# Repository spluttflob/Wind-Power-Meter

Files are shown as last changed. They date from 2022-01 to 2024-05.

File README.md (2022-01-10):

# Wind-Power-Meter
Hardware and software for a Raspberry Pi hat which measures the power produced by one or two small wind turbines.

## Hardware
The hardware consists of a circuit board designed in the style of a Raspberry
Pi HAT, but it's not an official HAT because an identifier ROM which is part of
the HAT specification isn't present.  Call it a "Cap" or something. 

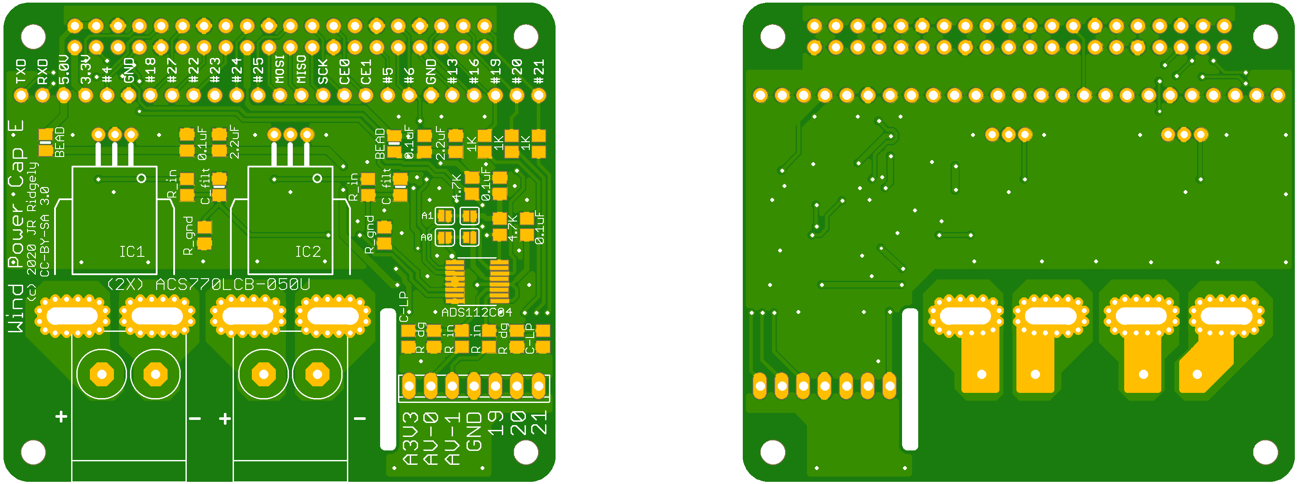
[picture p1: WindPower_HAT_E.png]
Images of Circuit Board


The board was designed in the standalone version of Autodesk&trade; Eagle PCB
and the schematic and board files are in the `hardware` directory.

The board uses a pair of Hall-effect current sensors to measure the current
output of the wind turbine; it is expected that the output will be somewhat
dirty DC, and simple filtering is provided.  Voltage dividers reduce the
voltage output of the turbine to safe levels.  Voltage and current are then
digitized with an ADS112C04 analog to digital converter that talks over an
I<sup>2</sup>C interface with the Raspberry Pi. 

## Software
It's just a Python program which gets data from the ADS112C04 and plots some 
plots. 

The software documentation page is at 
<https://spluttflob.github.io/Wind-Power-Meter/>.

### Pi Setup
When setting up a Raspberry Pi, one must enable the I<sup>2</sup>C interface 
using `raspi-setup` or the **Raspberry Pi Configuration** program from the 
desktop's applications menu.  It's often a good idea to enable **SSH**, the 
**VNC** remote desktop, and **SPI** as well. 

This software is designed to run on a "headless" Raspberry Pi. It has been
tested on the October 2021 release of Raspberry Pi OS. 
There's a nice page showing how to set up a "headless" (no monitor) Raspberry
Pi at 
<https://www.tomshardware.com/reviews/raspberry-pi-headless-setup-how-to,6028.html>.

### Dependencies

One needs the **PySimpleGUI** package for plotting as well as **Matplotlib**. 

* To install Matplotlib, run `sudo apt install python3-matplotlib` on the Pi.

* To install PySimpleGUI, run `sudo pip3 install pysimplegui` on the Pi.

* The web application is still being debugged.  It might help to run 
  `sudo pip3 install pysimpleguiweb htmlparser` on the Pi to begin. 

### VNC Issues
The Remmina client on a Linux PC has problems authenticating with the VNC 
desktop server on the Pi unless one adds the line `Authentication=VncAuth` 
to the file `/root/.vnc/config.d/vncserver-x11` on the Pi and then restarts 
the VNC server on the Pi with a command such as 
`systemctl restart vncserver-x11-serviced` (or a reboot). 

Other clients such as those for Windows&trade; or MacOS&trade; may or may not 
require such action to be taken.

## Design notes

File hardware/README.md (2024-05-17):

# Hardware

Here are a schematic and board layout done in standalone Autodesk&trade; Eagle PCB.
They should be easy to import into the Fusion 260&trade; version of Eagle
or into KiCAD (recommended). 

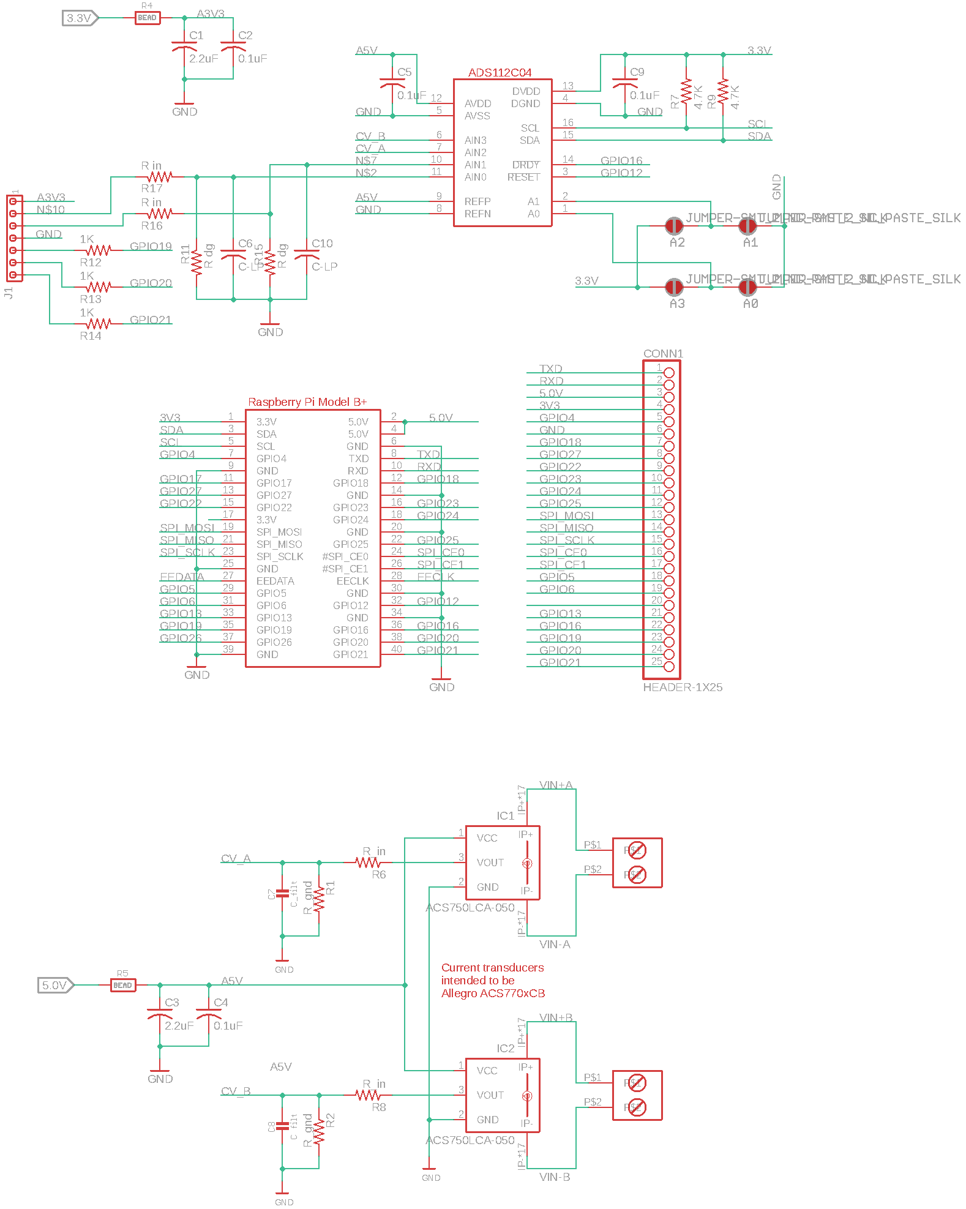
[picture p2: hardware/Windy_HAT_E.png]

_An image of the schematic for somewhat convenient reference._

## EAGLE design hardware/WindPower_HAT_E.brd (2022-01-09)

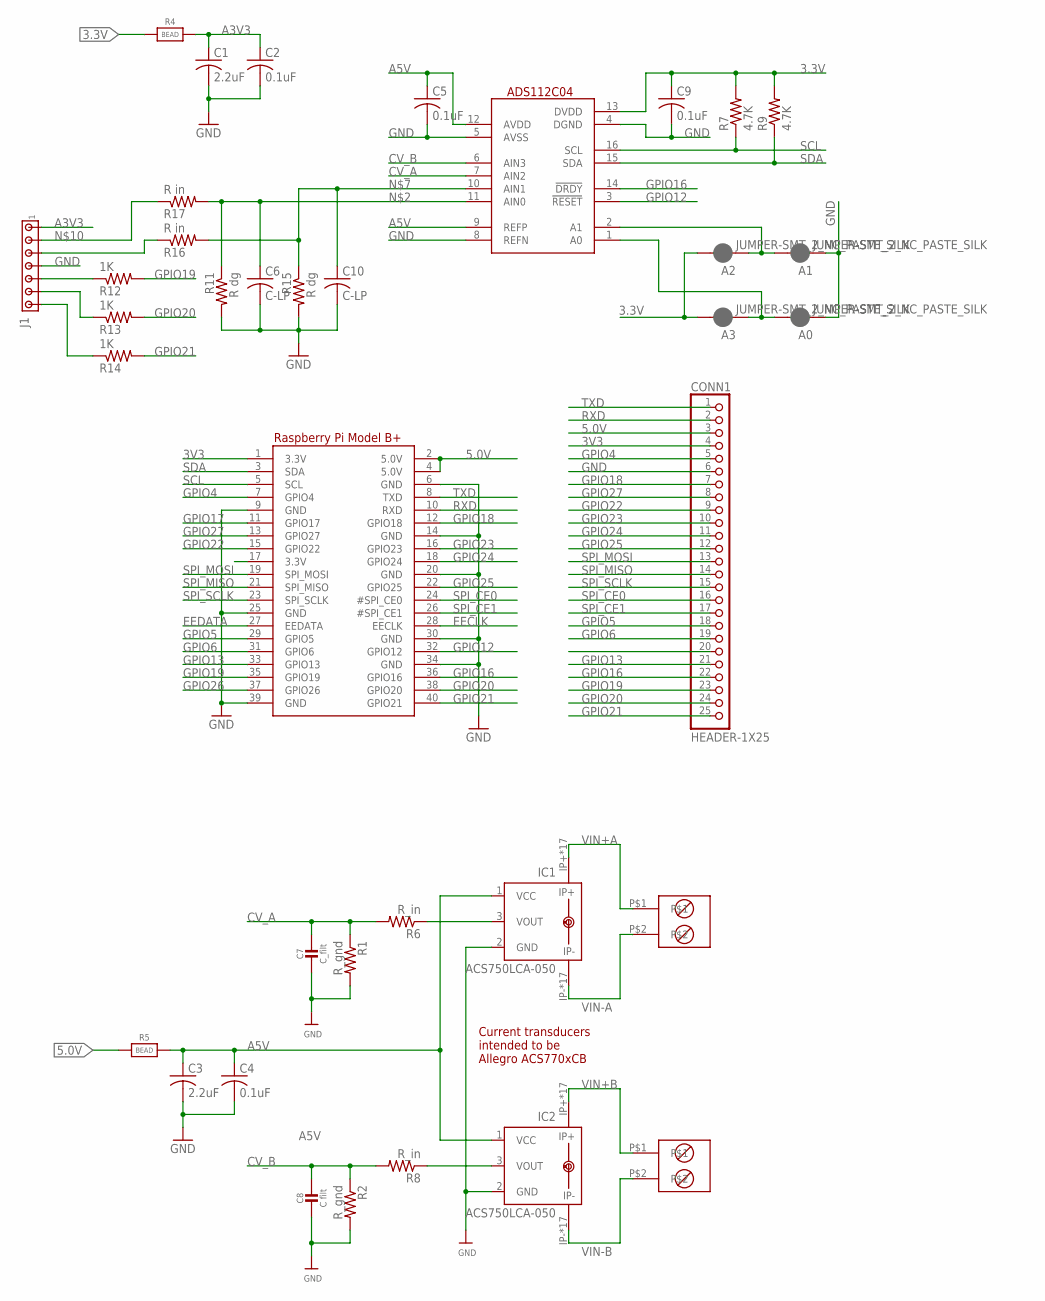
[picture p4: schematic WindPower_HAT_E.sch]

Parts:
A0, A1, A2, A3: JUMPER-SMT_2_NC_PASTE_SILK; SMT-JUMPER_2_NC_PASTE_SILK
ADS112C04: ADS112C04TSSOP_FOR_TI_ADC; SOP65P640X120-16N
C1, C3: 2.2uF; C0805
C2, C4, C5, C9: 0.1uF; C0805
C6, C10: C-LP; C0805
C7: C_filt; 0805-NO@1
C8: C filt; 0805-NO@1
CONN1: HEADER-1X25; 1X25_ROUND_70MIL
IC1, IC2: ACS750LCA-050; ACS75050
J1: MTA07-100; 10X07MTA
R1, R2: R_gnd; R0805
R4, R5: BEAD; 0805-NO
R6, R8: R_in; R0805
R7, R9: 4.7K; R0805
R11, R15: R dg; R0805
R12, R13, R14: 1K; R0805
R16, R17: R in; R0805
RPI1: RASPBERRYPI_BPLUS_HATNOSLOTS; PI_HAT_NOSLOTS
U$4, U$5: SCREW-2-6.35MM; SCREWY-2-6.35MM

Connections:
3.3V: A2.2, A3.2, ADS112C04.13 (DVDD), C9.1, R4.1, R7.2, R9.2, RPI1.17 (3.3V)
3V3: CONN1.4, RPI1.1 (3.3V)
5.0V: CONN1.3, R5.1, RPI1.2 (5.0V), RPI1.4 (5.0V)
A3V3: C1.1, C2.1, J1.1, R4.2
A5V: ADS112C04.9 (REFP), ADS112C04.12 (AVDD), C3.1, C4.1, C5.1, IC1.1 (VCC), IC2.1 (VCC), R5.2
CV_A: ADS112C04.7 (AIN2), C7.1, R1.1, R6.2
CV_B: ADS112C04.6 (AIN3), C8.1, R2.1, R8.2
EECLK: RPI1.28 (EECLK)
EEDATA: RPI1.27 (EEDATA)
GND: A0.1, A1.1, ADS112C04.4 (DGND), ADS112C04.5 (AVSS), ADS112C04.8 (REFN), C1.2, C2.2, C3.2, C4.2, C5.2, C6.2, C7.2, C8.2, C9.2, C10.2, CONN1.6, CONN1.20, IC1.2 (GND), IC2.2 (GND), J1.4, R1.2, R2.2, R11.2, R15.2, RPI1.6 (GND), RPI1.9 (GND), RPI1.14 (GND), RPI1.20 (GND), RPI1.25 (GND), RPI1.30 (GND), RPI1.34 (GND), RPI1.39 (GND)
GPIO4: CONN1.5, RPI1.7 (GPIO4)
GPIO5: CONN1.18, RPI1.29 (GPIO5)
GPIO6: CONN1.19, RPI1.31 (GPIO6)
GPIO12: ADS112C04.3 (!RESET), RPI1.32 (GPIO12)
GPIO13: CONN1.21, RPI1.33 (GPIO13)
GPIO16: ADS112C04.14 (!DRDY), CONN1.22, RPI1.36 (GPIO16)
GPIO17: RPI1.11 (GPIO17)
GPIO18: CONN1.7, RPI1.12 (GPIO18)
GPIO19: CONN1.23, R12.2, RPI1.35 (GPIO19)
GPIO20: CONN1.24, R13.2, RPI1.38 (GPIO20)
GPIO21: CONN1.25, R14.2, RPI1.40 (GPIO21)
GPIO22: CONN1.9, RPI1.15 (GPIO22)
GPIO23: CONN1.10, RPI1.16 (GPIO23)
GPIO24: CONN1.11, RPI1.18 (GPIO24)
GPIO25: CONN1.12, RPI1.22 (GPIO25)
GPIO26: RPI1.37 (GPIO26)
GPIO27: CONN1.8, RPI1.13 (GPIO27)
unnamed: IC1.3 (VOUT), R6.1
unnamed: ADS112C04.11 (AIN0), C6.1, R11.1, R17.2
unnamed: IC2.3 (VOUT), R8.1
unnamed: J1.5, R12.1
unnamed: J1.6, R13.1
unnamed: J1.7, R14.1
unnamed: ADS112C04.10 (AIN1), C10.1, R15.1, R16.2
unnamed: A1.2, A2.1, ADS112C04.2 (A1)
unnamed: A0.2, A3.1, ADS112C04.1 (A0)
unnamed: J1.2, R17.1
unnamed: J1.3, R16.1
RXD: CONN1.2, RPI1.10 (RXD)
SCL: ADS112C04.16 (SCL), R7.1, RPI1.5 (SCL)
SDA: ADS112C04.15 (SDA), R9.1, RPI1.3 (SDA)
SPI_CE0: CONN1.16, RPI1.24 (#SPI_CE0)
SPI_CE1: CONN1.17, RPI1.26 (#SPI_CE1)
SPI_MISO: CONN1.14, RPI1.21 (SPI_MISO)
SPI_MOSI: CONN1.13, RPI1.19 (SPI_MOSI)
SPI_SCLK: CONN1.15, RPI1.23 (SPI_SCLK)
TXD: CONN1.1, RPI1.8 (TXD)
VIN+A: IC1.IP+, IC1.IP+@2 (IP+), IC1.IP+@3 (IP+), IC1.IP+@4 (IP+), IC1.IP+@5 (IP+), IC1.IP+@6 (IP+), IC1.IP+@7 (IP+), IC1.IP+@8 (IP+), IC1.IP+@9 (IP+), IC1.IP+@10 (IP+), IC1.IP+@11 (IP+), IC1.IP+@12 (IP+), IC1.IP+@13 (IP+), IC1.IP+@14 (IP+), IC1.IP+@15 (IP+), IC1.IP+@16 (IP+), IC1.IP+@17 (IP+), U$4.P$1
VIN+B: IC2.IP+, IC2.IP+@2 (IP+), IC2.IP+@3 (IP+), IC2.IP+@4 (IP+), IC2.IP+@5 (IP+), IC2.IP+@6 (IP+), IC2.IP+@7 (IP+), IC2.IP+@8 (IP+), IC2.IP+@9 (IP+), IC2.IP+@10 (IP+), IC2.IP+@11 (IP+), IC2.IP+@12 (IP+), IC2.IP+@13 (IP+), IC2.IP+@14 (IP+), IC2.IP+@15 (IP+), IC2.IP+@16 (IP+), IC2.IP+@17 (IP+), U$5.P$1
VIN-A: IC1.IP-, IC1.IP-@2 (IP-), IC1.IP-@3 (IP-), IC1.IP-@4 (IP-), IC1.IP-@5 (IP-), IC1.IP-@6 (IP-), IC1.IP-@7 (IP-), IC1.IP-@8 (IP-), IC1.IP-@9 (IP-), IC1.IP-@10 (IP-), IC1.IP-@11 (IP-), IC1.IP-@12 (IP-), IC1.IP-@13 (IP-), IC1.IP-@14 (IP-), IC1.IP-@15 (IP-), IC1.IP-@16 (IP-), IC1.IP-@17 (IP-), U$4.P$2
VIN-B: IC2.IP-, IC2.IP-@2 (IP-), IC2.IP-@3 (IP-), IC2.IP-@4 (IP-), IC2.IP-@5 (IP-), IC2.IP-@6 (IP-), IC2.IP-@7 (IP-), IC2.IP-@8 (IP-), IC2.IP-@9 (IP-), IC2.IP-@10 (IP-), IC2.IP-@11 (IP-), IC2.IP-@12 (IP-), IC2.IP-@13 (IP-), IC2.IP-@14 (IP-), IC2.IP-@15 (IP-), IC2.IP-@16 (IP-), IC2.IP-@17 (IP-), U$5.P$2

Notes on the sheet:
Current transducers intended to be Allegro ACS770xCB

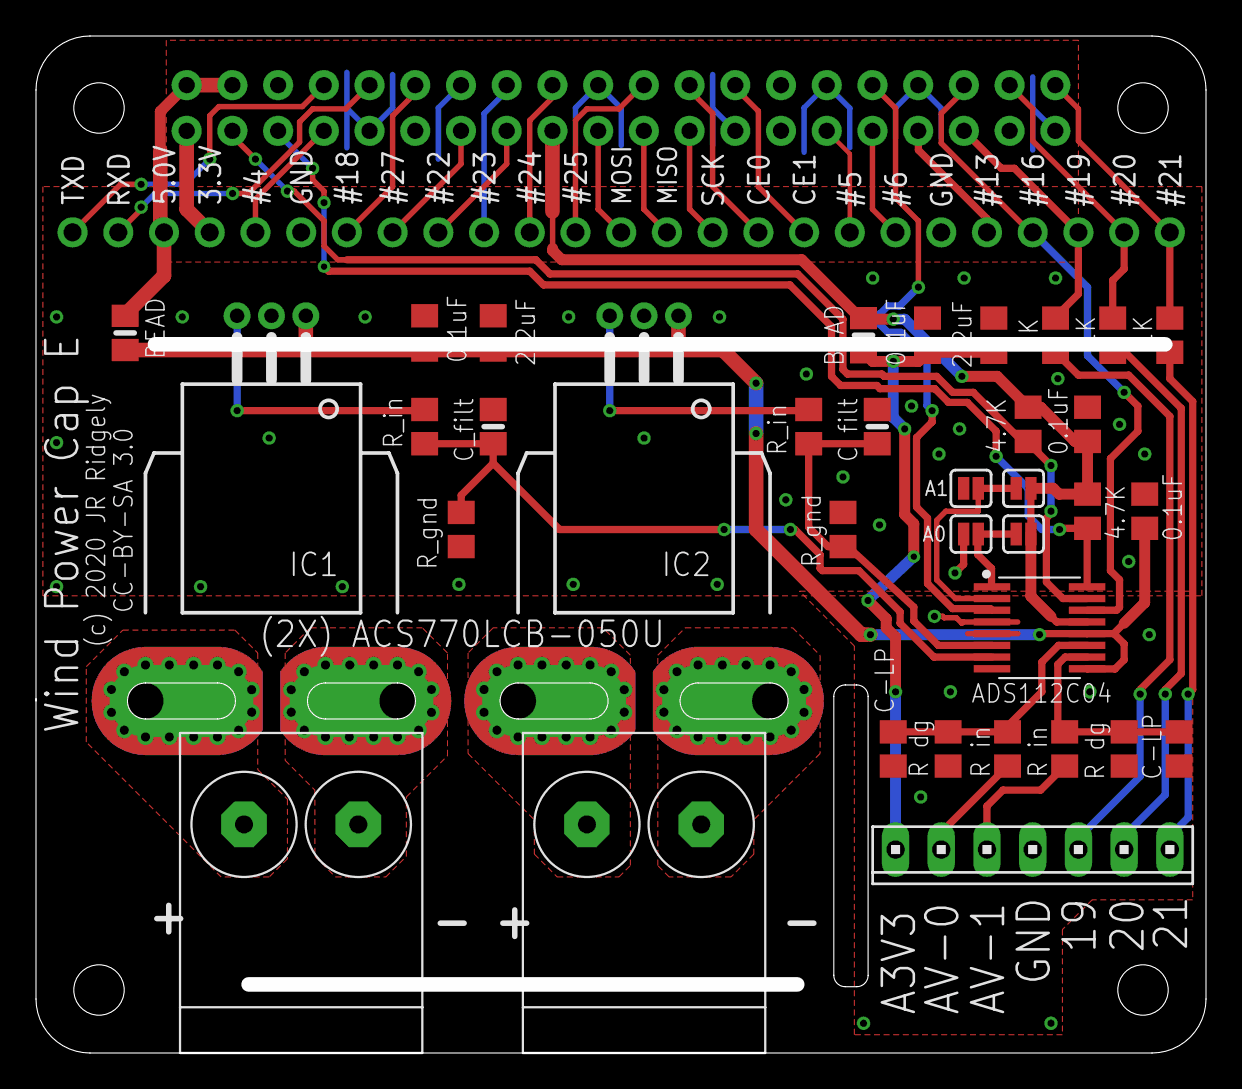
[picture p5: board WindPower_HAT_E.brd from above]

Board: 2 copper layers, 65.0 x 56.5 mm, 37 parts (0 on the bottom side), 47 nets.

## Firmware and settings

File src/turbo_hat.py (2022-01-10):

#!/usr/bin/python3
"""!
@file turbo_hat.py
    This file contains a driver for the Wind Turbine Power Measurement
    Sort-of-Pi-HAT which measures wind turbine power using a TI
    ADS112C04 ADC, some isolated current sensors, and voltage dividers.
@author    JR Ridgely
@date      2021-Jun-07 JRR Original file
@date      2022-Jan-08 JRR Updates to documentation for repository
@copyright Copyright (c) 2021-2022 by JR Ridgely and released under the
           Lesser GNU Public License, Version 3.
"""

import time
import RPi.GPIO as gpio
from smbus import SMBus      # This is I2C...?


class TurboHAT:
    """!
    This class drives a turbine power sensor on a Raspberry Pi Hat.
    The sensor uses a TI ADS112C04 A/D converter on I2C bus 1.
    """
    ## Reset the ADC
    CMD_RESET = 0x06
    ## Start or restart conversion
    CMD_START_SYNC = 0x08
    ## Power down the ADC
    CMD_PWR_DOWN = 0x02
    ## Load ADC output with data
    CMD_RDATA = 0x10
    ## Read a register; address in bits 3,2
    CMD_RREG = 0x20
    ## Write register; address in bits 3,2
    CMD_WREG = 0x40

    ## Configuration register 0
    REG_CFG_0 = 0x00
    ## Configuration register 1
    REG_CFG_1 = 0x01
    ## Configuration register 2
    REG_CFG_2 = 0x02
    ## Configuration register 3
    REG_CFG_3 = 0x03

    ## Internal 2.048 volt reference
    VREF_INT_2048 = 0x00
    ## External reference on REFP, REFN pins
    VREF_EXT = 0x02          
    ## Analog supply AVDD - AVSS used as reference
    VREF_SUP = 0x04          

    # Data rates for normal (not turbo) mode; in turbo, rates are doubled
    ## Data rate 20 Hz     
    DR_20HZ = 0x00           
    ## Data rate 45 Hz
    DR_45HZ = 0x20           
    ## Data rate 90 Hz
    DR_90HZ = 0x40           
    ## Data rate 175 Hz
    DR_175HZ = 0x60          
    ## Data rate 330 Hz
    DR_330HZ = 0x80          
    ## Data rate 600 Hz
    DR_600HZ = 0xA0          
    ## Data rate 1000 Hz
    DR_1000HZ = 0xC0         


    def __init__ (self, i2c_bus, i2c_address=0x40, reset_pin=12, drdy_pin=16,
                  ref_voltage=VREF_SUP, data_rate=DR_20HZ):
        """! Set up the GPIO ports to talk to the ADC and save the ADC's
        address on the I2C bus.
        @param i2c_bus The I2C bus used, created by "SMBus(1)" or similar
        @param i2c_address The ADC's address on the I2C bus
        @param reset_pin The GPIO pin connected to the ADC's RESET' line
        @param drdy_pin The GPIO pin connected to the ADC's DRDY' line
        @param ref_voltage The reference voltage source, chosen from the set
               of @c VREF_... constants given in this class
        @param data_rate The data rate in Hz for conversions, chosen from the
               set of @c DR_... constants given in this class
        """
        self._i2c_bus = i2c_bus
        self._address = i2c_address
        self._reset_pin = reset_pin
        self._drdy_pin = drdy_pin
        self._ref_voltage = ref_voltage
        self._data_rate = data_rate

        # Set pin numbering mode to use Broadcom pins (more commonly used)
        # Turbine measurement ADC pins: RESET' on GPIO12, DRDY' on GPIO16
        gpio.setwarnings (False)
        gpio.setmode (gpio.BCM)
        gpio.setup (self._reset_pin, gpio.OUT)
        gpio.setup (self._drdy_pin, gpio.IN, pull_up_down=gpio.PUD_UP)

        # Set the RESET' pin high so the ADC will operate
        gpio.output (self._reset_pin, gpio.HIGH)

        # Set the reference voltage and data rate in config. register 1
        self._i2c_bus.write_byte_data (self._address,
                        TurboHAT.CMD_WREG | (TurboHAT.REG_CFG_1 << 2),
                        self._ref_voltage | self._data_rate)


    def clean_up (self):
        """!
        Set the GPIO pins back to normal (input) mode and close the I2C bus.
        """
        gpio.cleanup ()
        self._i2c_bus.close ()


    def show_ADC_registers (self):
        """! Display the contents of the registers in the ADC. The read
        register command has bits 0010rrxx, where rr hold the address
        and xx don't seem to matter
        """
        for reggie in range (4):
            data = self._i2c_bus.read_byte_data (self._address,
                       TurboHAT.CMD_RDATA | (reggie << 2))
            print ("Reg {:d}: 0b{:08b}".format (reggie, data), end=' ')
        print ("")


    def read_channel (self, chan):
        """! Read one ADC channel. The value returned is a signed 16 bit
        number with the maximum corresponding to a voltage equal to the
        reference. Ref: https://www.abelectronics.co.uk/kb/article/1094/
                   i2c-part-4---programming-i-c-with-python
        @param chan The channel to read
        """
        # Set the multiplexer to select the correct channel for
        # a single-ended measurement
        self._i2c_bus.write_byte_data (self._address,
                        TurboHAT.CMD_WREG | (TurboHAT.REG_CFG_0 << 2),
                        (0x08 | (chan & 0x03)) << 4)

        # Send a start/sync command to begin reading
        self._i2c_bus.write_byte (self._address,
                                 TurboHAT.CMD_START_SYNC)

#         # Check the DRDY bit in configuration register 2 to see if the
#         # conversion is complete
#         counter = 0
#         while True:
#             cr2 = self._i2c_bus.read_byte_data (self._address,
#                 TurboHAT.CMD_RREG | (TurboPower.REG_CFG_2 << 2))
#             if cr2 & 0x80:
#                 break
#             else:
# #                 if not counter:
# #                     print ("CR2:", cr2)  ####################
#                 counter += 1
#                 if counter > 1000:
#                     raise IOError ("Timeout waiting for ADS112C04")
#                     break

        # Wait for the DRDY' line to go low
        counter = 0
        while gpio.input (self._drdy_pin):
            time.sleep (0.01)
            counter += 1
            if counter > 100000:
                raise IOError ("Timeout waiting for ADS112C04")
                break

        # Read and return the data, with bytes swapped
        adc_data = self._i2c_bus.read_word_data (self._address,
                                                TurboHAT.CMD_RDATA)
        return ((adc_data & 0x00FF) << 8) | ((adc_data & 0xFF00) >> 8)


def main ():
    """! Test the ADC somehow or other. This function isn't run when 
    this driver is imported as a module.
    """
    print ("Testing Turbine Power Sensors")

    i2c_bus = SMBus (1)
    turbo = TurboHAT (i2c_bus, i2c_address=0x40, reset_pin=12, drdy_pin=16)
    turbo.show_ADC_registers ()
#     turbo.show_ADC_registers ()
    for count in range (20):
        ch0data = turbo.read_channel (0)
        print ("Ch 0:", ch0data)
        time.sleep (1.0)

    turbo.show_ADC_registers ()

    turbo.clean_up ()


if __name__ == "__main__":
    main ()

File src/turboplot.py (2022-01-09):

"""!
@file turboplot.py
    This file contains a program which makes simple plots of wind
    turbine generation.

@author JR Ridgely
@date   2021-Jun-08 JRR Original file
@date   2022-Jan-08 JRR Updates to documentation for repository
"""

import io
import time
from smbus import SMBus
import PySimpleGUI as sg
from matplotlib.backends.backend_tkagg import FigureCanvasAgg
from matplotlib import figure, pyplot
from turbo_hat import TurboHAT


def create_plots(times, data, xlabel=None, ylabels=None,
                 plot_titles=None, title=None):
    """!
    Create a plot or plots with the given time array and list of data arrays.
    @param times An iterable of time axis coordinates
    @param data A list of iterables of vertical axis coordinates
    @param xlabel The label for the plot X axes
    @param ylabels An iterable of labels for plot Y axes
    @param plot_titles An iterable of titles of plots
    @param title An overall title for Life, the Universe, and Everything
    @returns A list of figures, one for each plot
    """
    pyplot.style.use("dark_background")

    # Figure out how many plots' worth of data are present and set
    # up that many subplots; for each subplot there may be more than
    # one series of data
    num_plots = len(data)

    figures = []

    for subplot_num in range(num_plots):
        fig = figure.Figure(figsize=(5, 4), dpi=100)
#         subplot_code = num_plots * 100 + 10 + (subplot_num + 1)
        axis = fig.add_subplot(111) ####### subplot_code)

        # Plot each of the series on this plot. Serieses?
        for series in data[subplot_num]:
            oneline = axis.plot(times, series)
        if xlabel:
            axis.set_xlabel (xlabel)
        if ylabels:
            axis.set_ylabel (ylabels[subplot_num])
        if plot_titles:
            axis.set_title (plot_titles[subplot_num])
#         if title:
#             fig.suptitle(title)
        figures.append(fig)

    return figures


def draw_figures(figures, elements):
    """!
    Draw the plots which have been created in create_plots().
    @param figures A list of figures containing the plots
    @param elements The screen elements on which the plots are drawn
    """
    for fig, elle in zip(figures, elements):
        canv = FigureCanvasAgg(fig)
        buf = io.BytesIO()
        canv.print_figure(buf, format='png')

        if buf is not None:
            buf.seek(0)
            data = buf.read()
            elle.update(data=data)


def print_data(times, data):
    """!
    This function prints (or displays) a set of turbine data.
    @param times A list of times
    @param data The list of lists of lists holding the data
    """
    for index in range(len(times)):
        print ("{:.3f},".format (times[index]), end='')
        for plot in data:
            for channel in plot:
                print ("{:.2f},".format (channel[index]), end='')
        print ("")


def main():
    """!
    Run the program.
    """
    data_period = 1.0              # Time between data acquisitions in seconds
    start_time = time.time()       # Save starting time for relative timing
    next_data_time = 0.0           # Time to take the next data point

    # Set up the power measurement hardware
    i2c_bus = SMBus (1)
    turbo = TurboHAT (i2c_bus, i2c_address=0x40, reset_pin=12, drdy_pin=16)

    # Create some arrays (well, lists) for time and voltage data. Times
    # are a simple array. Data is arranged as an array of subplots, each
    # of which contains a list of channels. Variables 'data', 'channels',
    # and 'legends' must have matching dimensions
    times = []
    data = [[[], []], [[], []]]
    channels = [[0, 2], [1, 3]]
    legends = [['Turbine 1 Voltage', 'Turbine 1 Current'],
               ['Turbine 2 Voltage', 'Turbine 2 Current']]
    x_label = "Time (s)"
    y_labels = ["Ch 0,2 V", "Ch 1,3 V"]          # One per subplot
    plot_titles = ["Turbine 1", "Turbine 2"]
    plots_title = "Wind Turbine Power"

    # Specify calibration for each ADC channel; this flat list just
    # gives numbers for channels 0 through 3 in order
    calibrations = [5.0 / 32768, 5.0 / 32768, 5.0 / 32768, 5.0 / 32768]

    # Make a flat list of channels and a set of columns for printing 'em.
    # The columns must be in a list of lists of lists. Really
    flat_channels = [item for sublist in channels for item in sublist]
    chan_labs = [[[sg.Text("Ch. {:d}".format(num), size=(16, 1),
                           font=("Helvetica", 12), justification="center")
                   for num in flat_channels]]]
    chan_cols = [[[sg.Text(key="-CH{:d}-".format(num), size=(16, 1),
                           font=("Helvetica", 12), justification="center")
                   for num in flat_channels]]]

    # Choose a theme for the plots, or don't for the boring default
    sg.theme ("DarkGrey5")

    # ------------------------------------------------------------------------
    # Set up the screen layout and main window

    # Indicators for the readings from the channels
    layout = [[[sg.Column(col) for col in chan_labs]],
              [[sg.Column(col) for col in chan_cols]]]

    # The place where the plots will go
    layout.append([[sg.Image(key="-PLOT{:d}-".format(plot_num))
                  for plot_num in range(len(data))]])

    # A row of control buttons
    layout.append([[sg.Button("Clear"),
                    sg.Button("Save Plots"),
                    sg.Button("Save Data"),
                    sg.Button("Exit")]])

    window = sg.Window("Turbine Power", layout)

    # Make a list of plot windows; it's used when drawing plots onscreen
    plot_windows = [window['-PLOT{:d}-'.format(x)] for x in range(len(data))]

    # ------------------------------------------------------------------------
    # Run the event loop with a timer so data is read every second
    while True:
        event, values = window.read(timeout=1000)

        # If the program is exiting, break out of the event loop
        if event == 'Exit' or event == sg.WIN_CLOSED:
            break

        # If the 'Clear' button was pressed, empty the data arrays
        # except for the most recent point(s)
        if event == 'Clear':
            try:
                del times[:-1]
                for subplot in data:
                    for oneplot in subplot:
                        del oneplot[:-1]
            except IndexError:
                print ("Attempt to clear empty data arrays")
                pass

        # If the 'Save Data' button was pressed, do it
        if event == "Save Data":
            print_data(times, data)

        else:
            # Check that it's time to acquire some more data
            now_time = time.time() - start_time
            if now_time > next_data_time:
                next_data_time += data_period
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

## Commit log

2022-01-09 Organized code, added docs, made a README
    [WindPower_HAT_E.brd, WindPower_HAT_E.sch]
2022-01-10 Fixed a typo in turbo_hat.py, updated readme
    [turbo_hat.py]
2022-01-10 Fixed a bug in readme which hid the circuit boards
2024-05-17 Added README and image of schematic to hardware section

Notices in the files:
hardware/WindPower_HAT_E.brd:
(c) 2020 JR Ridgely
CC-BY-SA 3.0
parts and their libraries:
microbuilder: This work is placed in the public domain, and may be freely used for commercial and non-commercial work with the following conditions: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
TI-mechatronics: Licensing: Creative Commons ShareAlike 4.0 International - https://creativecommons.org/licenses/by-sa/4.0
